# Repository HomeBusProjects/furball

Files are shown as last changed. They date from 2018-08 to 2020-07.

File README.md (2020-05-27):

# The Furball



Furball is an open-source hardware project intended to help with the research and development of [Homebus](https://github.com/HomeBusProjects), an IoT auto-provisioning framework and data processing network built on top of MQTT. Note that Homebus is not even alpha quality software at this time and is still undergoing architectural changes and development.

The name 'Furball' is an homage to Dave Mills' ["Fuzzball"](https://en.wikipedia.org/wiki/Fuzzball_router), one of the first routers on the nascent Internet.

The Furball hardware performs environmental monitoring and is intended to be deployed indoors with fixed power source. It will auto-provision with Homebus to feed sensor readings into an IoT system.

## Hardware

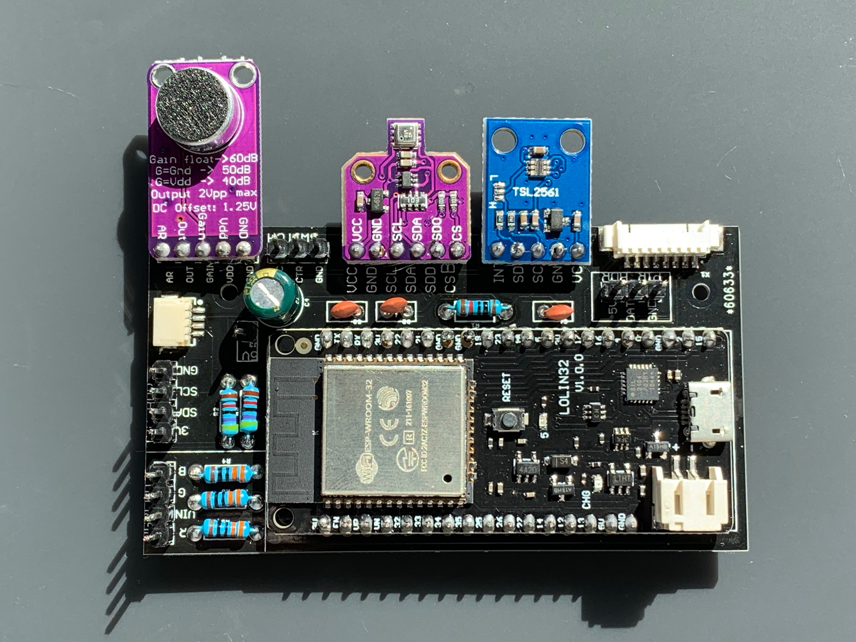
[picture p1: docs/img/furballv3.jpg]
An assembled Furball


Furball is based on the ESP32 processor. ESP32 is more capable than its predecessor, the ESP8266 while remaining inexpensive. The ESP32 supports both 802.11b/g/n Wifi and Bluetooth 4.2/BLE. It also has hardware acceleration for encryption. It includes 4 SPI controllers, 2 I2C controllers, 3 UARTs, up to 18 channels of ADC and two 8 bit DACs. You'll never use all of those at once as it doesn't have enough GPIO pins to express all of those functions, though you can map many of the hardware controllers to particular GPIO pins.

The hardware supports several environmental sensors:
- temperature
- humidity
- air pressure 
- light intensity
- occupancy 
- sound intensity
- volatile organics

It's powered via USB. The hardware currently uses a LOLIN32 board which has a JST connector for a LiPo battery. The software is currently in no way optimized for battery operation.

The hardware also includes either a tri-color LED or RGB LED with controller.

While the Furball hardware is designed to work with the Furball software, it should also work with other software like [ESPEasy32](https://www.letscontrolit.com/wiki/index.php?title=ESPEasy32), [ESPHome](https://esphome.io/) or custom software.

See the [Furball Hardware Guide](HARDWARE.md) for assembly instructions.

### Temperature, Humidity and Pressure

Furball currently uses the [BME280](https://www.bosch-sensortec.com/products/environmental-sensors/humidity-sensors-bme280/) - temperature/pressure/humidity sensor, $2.57 in single unit quantities, AliExpress, or the [BME680](https://www.bosch-sensortec.com/products/environmental-sensors/gas-sensors-bme680/) - temperature/pressure/humidity/VOC sensor, $9.92 in single unit quanitties on AliExpress.

### Occupancy

Furball hardware has a 3 pin header for a [PIR](https://en.wikipedia.org/wiki/Passive_infrared_sensor) sensor.

### Sound Pressure

Furball hardware currently uses a small amplified microphone on a breakout board, compatible with [Sparkfun's Sound Detector](https://www.sparkfun.com/products/12642).

### Light

Furball uses the [TSL2561](https://ams.com/tsl2561)  Digital Luminosity sensor - $1 in single unit quantities, AliExpress.

### VOC

Furball uses the BME680, which is a BME280 plus a VOC sensor. If you're building a Furball which can read VOCs, you only need the BME680 and not the BME280.

(note: I originally used a [CCS811](https://ams.com/ccs811) but had a lot of problems with cheaper units. It also doesn't truly measure CO2 but infers it from the VOC reading.)

### Total Cost

If bought through AliExpress, parts cost should run roughly:
- $6 - ESP32 LOLIN32
- $2.57 - BME280
- $1 - TSL2561
- $9 - BME680
- $1 - random resistors, capacitors, tri-color LED

Total of roughly $20 in parts before the circuit board.

## Optional Hardware

### Particle sensor

Furball has an optional port to connect a Plantower [PMS5003](http://www.plantower.com/en/content/?108.html) particle sensor. The particle sensor allows you to monitor air quality.

## Software

Furball's software is built on the Arduino Core using [PlatformIO](https://platformio.org/) as its build system. I prefer PlatformIO because it's fast, has a good library manager, lets you build for arbitrary platforms without having to manually install support for them, and lets you use your editor of choice.

Create a `src/config.h` file based on `src/config.h-example` and configure Wifi and the MQTT broker.

Once you've installed PlatformIO you can build the Furball firmware by running:
```
platformio run
```

in its top level directory.

To flash the firmware, run:
```
platformio run -t upload
```

It currently supports OTA updates.

## Iterations

The intial version is a simple breadboard.

Second version is a soldered printed circuit breadboard.

The third and current version will be a custom printed circuit board with modules soldered into it.

A hypothetical fourth version would be a custom printed circuit board with surface mount components and will have components mounted directly on it rather than using 3rd party modules.

# License

Software and documentation is licensed under the [MIT license](https://romkey.mit-license.org/).

Circuits are licensed under [Creative Commons Attribution Share-Alike license](https://creativecommons.org/licenses/by-sa/4.0).

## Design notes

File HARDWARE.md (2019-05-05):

# Furball Hardware Guide

The Furball is based on an ESP32 processor.

The ESP32 supports IEEE802.11b/g/n wifi as well as Bluetooth 4.0 and BLE.

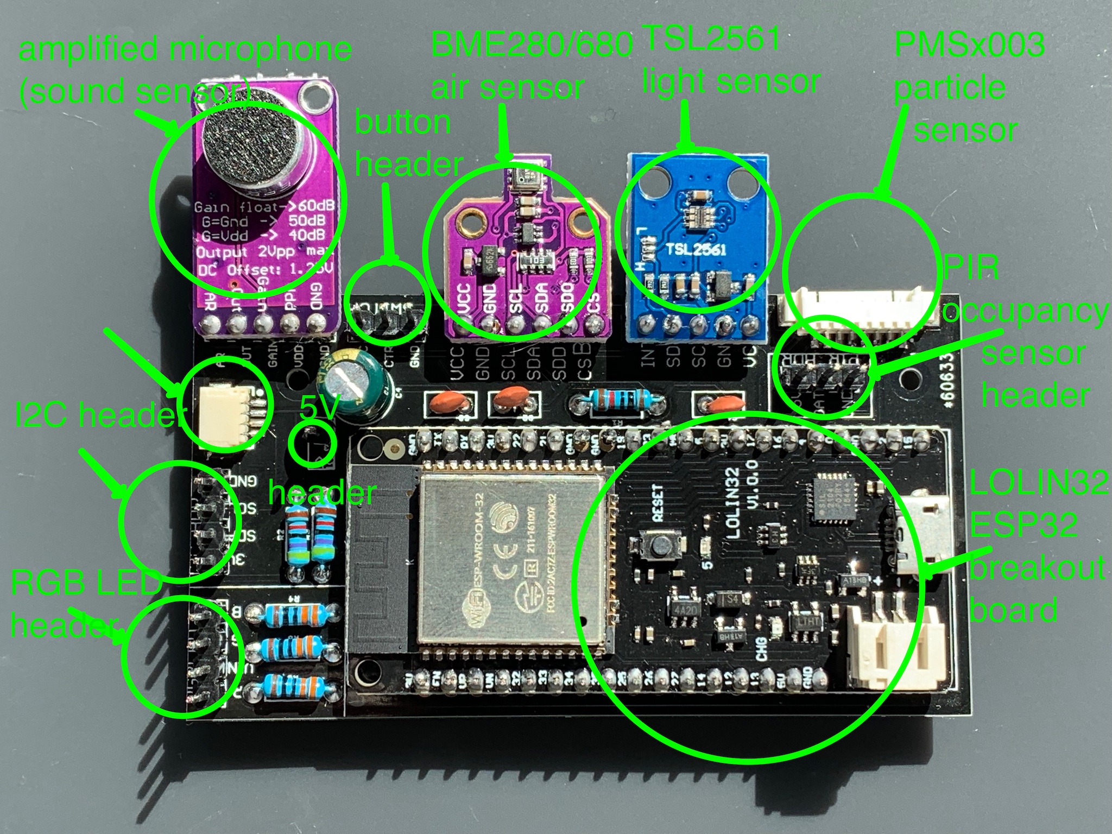
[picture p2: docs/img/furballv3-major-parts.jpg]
Furball's major parts


Furball uses I2C to communicate with a BME280 (air temperature, humidity and pressure) or BME680 (air temperature, humidity, pressure and volatile organics) and a TSL2561 (light intensity).

It also expresses the I2C bus via both a 4 pin header and a Sparkfun QUICC connector so that you can easily add external I2C devices if you want.

Furball also has a connector for a PMS5003 particle counter (via a 9600bps serial connection) and a PIR occupancy detector (via a digital input).

Furball can controll an RGB LED and can read the state of an switch (intended as a reset/factory reset button).

All of these are optional. Furball can detect the presence of a BME280, BME680, TSL2561 or external I2C device (external devices will need software support). It cannot detect whether a PIR sensor, RGB LED or switch is connected. The software also cannot currently detect whether a PMS5003 is connected but this may change with future releases.

## The printed circuit board

The Furball v4 board was designed using [Autodesk Eagle](https://www.autodesk.com/products/eagle/overview). The Eagle files are in the `eagle` directory of this repository. The board is small enough that the free version of Eagle works.

There are currently no known issues with the board but I cannot guarantee it will work 100% correctly and that no issues will be found in the future. *Use at your own risk*.

The board would benefit from better documentation on its silkscreen (resistors and capacitors are not well-labelled).

## Assembly

1. The PMS5003 and Sparkfun QUIIC connectors are both surface mount and for most people will be the most challenging part of assembling this board. They're both optional. If you're going to use them, I recommend soldering them first.  

  The technique I use is to apply solder to all the pads for both connectors using a fine tip on the soldering iron and fine solder (0.6mm).  

  Then carefully, using your fingertips or needle nose pliers or tweezers, position the connector on top of the pads and use the soldering iron to melt one of the sides. Let that cool and then carefully melt each connection until the entire connector has solid contact with the board and solder.

2. Solder headers on the ESP32 breakout board as well as the other boards that I'm using in the project.

3. Solder the ESP32 breakout board onto the printed circuit board.

4. If you're using it, solder the TSL2561 breakout board onto the main board. Then I flash the board with the [ESP32 diagnostic](), run an I2C scan and confirm that the ESP32 can see the TSL2561. If it cannot, inspect the board for bad solder joints or shorts.

5. If you're using it, solder the BME280 or BME680 onto the board and run the ESP32 diagnostic and confirm that the ESP32 can see it and (if used) the TSL2561. Resolve any problems before proceeding.

6. Solder the microphone breakout board, if being used.

7. Next, solder the resistors and capacitors on the board.

- three 330 ohm resistors
- two 47K ohm resistors
- one 10k ohm resistor
- three 10pF capacitors
- one 100

This is a good time to run the diagnostic again in order to make sure the board still works.

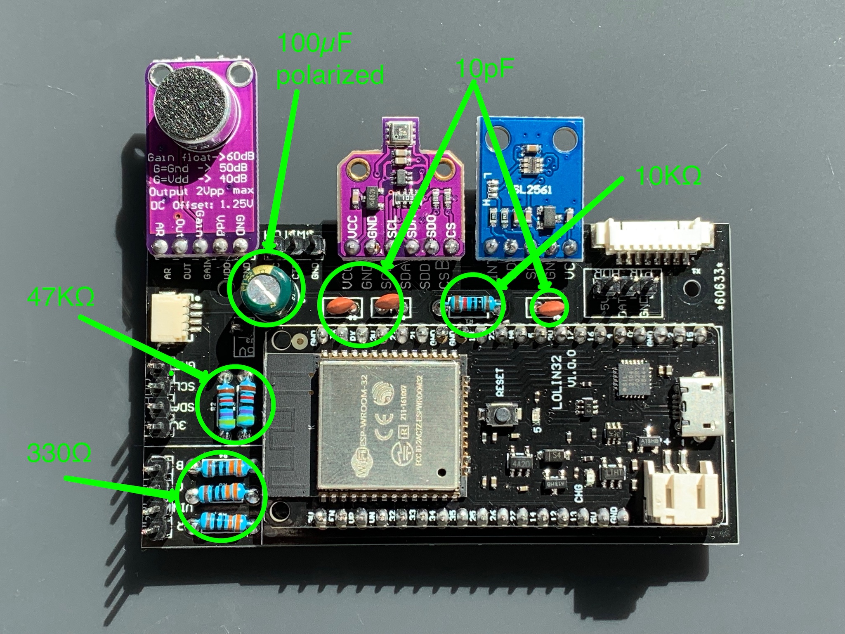
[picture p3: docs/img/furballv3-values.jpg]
Furball's resistors and capacitors


8. Finally, solder whichever headers you want to use. You can ignore ones you don't need, and you can always add them later if you want.

- external I2C - 4 pins
- RGB LED - 4 pins
- PIR sensor - 3 pins
- switch - 3 pins
- 5V - 1 pin

9. Run the diagnostic a final time and resolve any problems.

10. Build and flash the Furball firmware and watch its output to confirm that the board is working properly.

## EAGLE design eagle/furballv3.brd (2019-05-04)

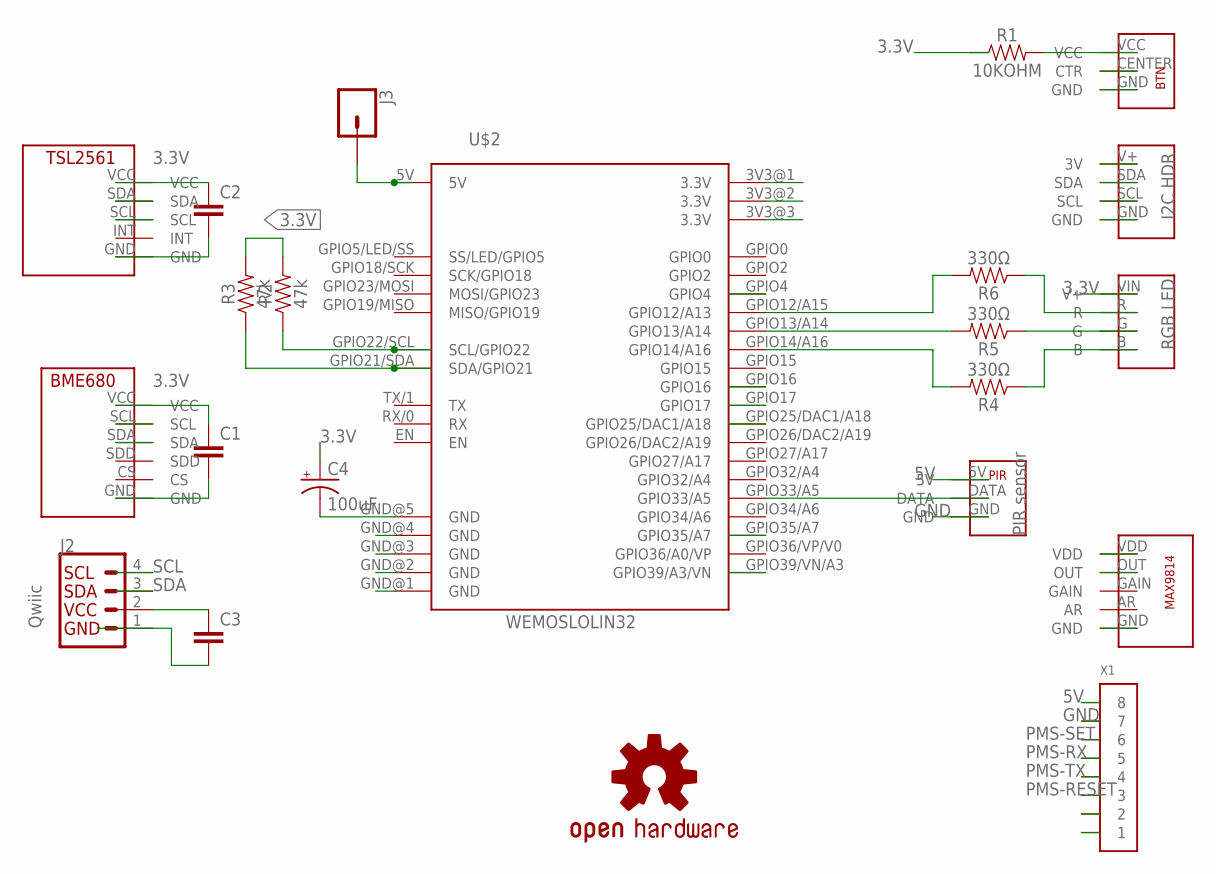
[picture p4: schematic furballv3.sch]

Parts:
C1, C2, C3: 10pF; CAP-PTH-SMALL2
C4: 100uF; CPOL-RADIAL-2.5MM-6.5MM
J2: QWIIC_CONNECTORJS-1MM; 1X04_1MM_RA
J3: CONN_01; 1X01
LOGO1: OSHW-LOGOL; OSHW-LOGO-L
R1: 10KOHM; AXIAL-0.3-KIT
R2, R3: 47k; AXIAL-0.3
R4, R5, R6: 330Ω; AXIAL-0.3
U$1: PIRHEADER
U$2: WEMOSLOLIN32; LOLIN32VAR1
U$3: BME680BREAKOUT
U$4: TSL2561BREAKOUT
U$5: RGBLEDHEADER; RGBLEDHDR
U$6: I2CHEADER
U$7: MAX9814BREAKOUT
U$8: PUSHBUTTONHEADER
X1: CONN_8-1-53261; PB-53261-08

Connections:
3.3V: C1.1, C2.1, C3.1, C4.1 (+), J2.2 (VCC), R1.P$1 (1), R2.P$2 (2), R3.P$2 (2), U$2.3V3@1 (3.3V), U$2.3V3@2 (3.3V), U$2.3V3@3 (3.3V), U$3.VCC, U$4.VCC, U$5.VIN (V+), U$6.V+ (3V), U$7.VDD
5V: J3.1, U$1.5V, U$2.5V, X1.8
BUTTON: U$2.GPIO35/A7, U$8.CENTER (CTR)
GND: C1.2, C2.2, C3.2, C4.2 (-), J2.1 (GND), U$1.GND, U$2.GND@1 (GND), U$2.GND@2 (GND), U$2.GND@3 (GND), U$2.GND@4 (GND), U$2.GND@5 (GND), U$3.GND, U$4.GND, U$6.GND, U$7.GND, U$8.GND, X1.7
unnamed: R5.P$1 (1), U$5.G
unnamed: R6.P$2 (2), U$2.GPIO12/A15 (GPIO12/A13)
unnamed: U$1.DATA, U$2.GPIO33/A5
unnamed: R5.P$2 (2), U$2.GPIO13/A14
unnamed: R4.P$2 (2), U$2.GPIO14/A16
unnamed: R4.P$1 (1), U$5.B
unnamed: R6.P$1 (1), U$5.R
unnamed: R1.P$2 (2), U$8.VCC
PMS-RESET: U$2.GPIO25/DAC1/A18, X1.3
PMS-RX: U$2.GPIO16, X1.5
PMS-SET: U$2.GPIO4, X1.6
PMS-TX: U$2.GPIO17, X1.4
SCL: J2.4 (SCL), R2.P$1 (1), U$2.GPIO22/SCL (SCL/GPIO22), U$3.SCL, U$4.SCL, U$6.SCL
SDA: J2.3 (SDA), R3.P$1 (1), U$2.GPIO21/SDA (SDA/GPIO21), U$3.SDA, U$4.SDA, U$6.SDA
SOUND: U$2.GPIO39/VN/A3 (GPIO39/A3/VN), U$7.OUT

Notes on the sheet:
Qwiic
PIR sensor
RGB LED
I2C HDR

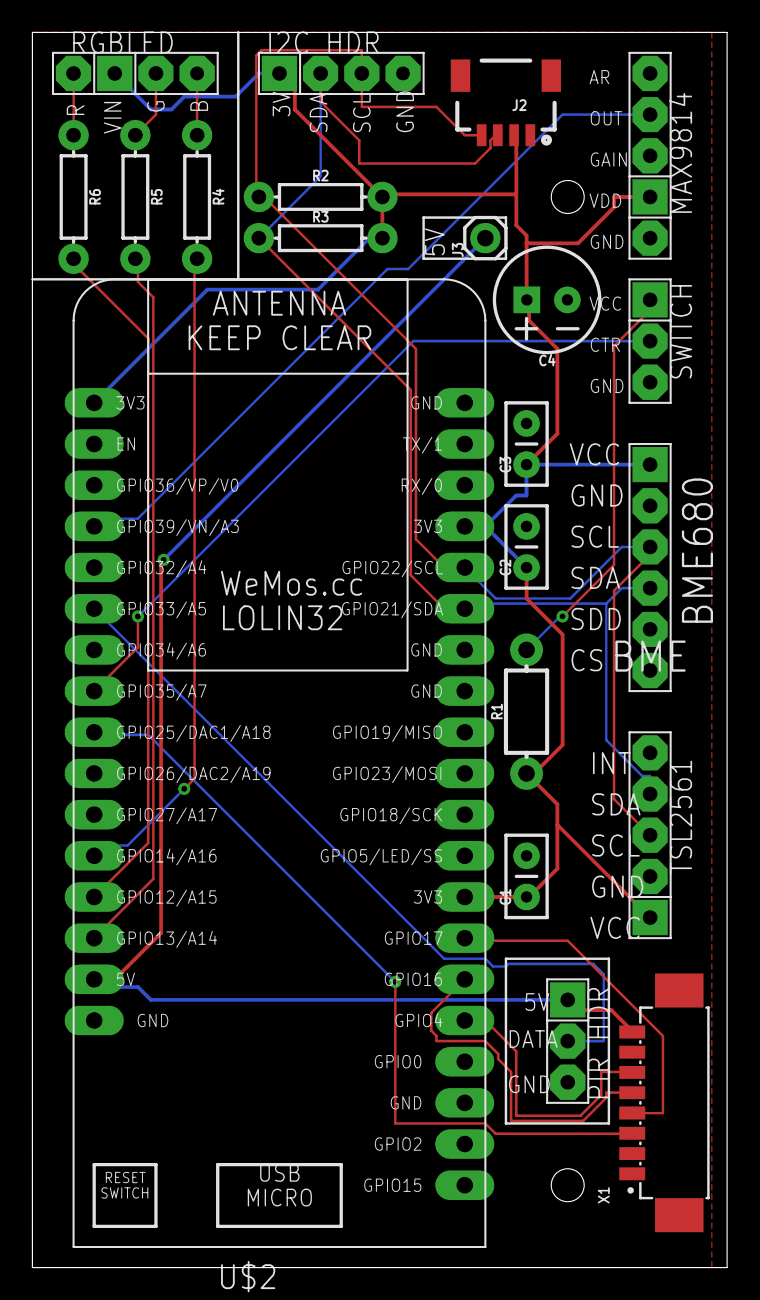
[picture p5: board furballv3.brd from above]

Board: 2 copper layers, 42.9 x 76.2 mm, 22 parts (1 on the bottom side), 19 nets.

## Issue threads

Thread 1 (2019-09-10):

Don't publish values for missing sensors

romkey, 2019-09-10:

romkey, 2020-02-19:
If a sensor isn't present, don't publish the DDC for the sensor.  For instance, if the light sensor isn't found, don't publish the 'org.homebus.light' DDC.

Closed 2020-06-27.

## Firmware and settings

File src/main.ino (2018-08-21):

#include <Arduino.h>

#include <ESP.h>
#include <ESPmDNS.h>
#include <WiFi.h>
#include <HTTPClient.h>

#include "config.h"

#include <ArduinoOTA.h>

#include "bme280_sensor.h"
#include "ccs811_sensor.h"
#include "tsl2561_sensor.h"
#include "adxl345_sensor.h"
#include "lis3dh_sensor.h"
#include "pms_sensor.h"

#include "pir_sensor.h"
#include "sound_level_sensor.h"

#define BUTTON_PIN 33
#define PIR_PIN 34
#define SOUND_PIN 35

BME280_Sensor bme280(UPDATE_DELAY, 0, 0, false);
CCS811_Sensor ccs811(UPDATE_DELAY, 0, 0, false);
TSL2561_Sensor tsl2561(UPDATE_DELAY, 0, 0, false);
ADXL345_Sensor adxl345(UPDATE_DELAY, 0, 0, false);
LIS3DH_Sensor lis3dh(UPDATE_DELAY, 0, 0, false);
PMS_Sensor pms5003(UPDATE_DELAY, 0, 0, false);

PIR_Sensor pir(1, UPDATE_DELAY, 0, 0, false);
SoundLevel_Sensor sound_level(SOUND_PIN, UPDATE_DELAY, 0, 0, false);

#include "uptime.h"

Uptime uptime;

#include <JC_Button.h>   

Button the_button(BUTTON_PIN);

// HomeBus is not ready for Prime Time so leave this out for now
#ifdef HOMEBUS

#include <HomeBus.h>
#include <HomeBusDevice.h>

HomeBus hb("Furball One",
	   "an esp8266 far, far away",
	   "HomeBus Central",
	   "0.0.1",
	   WiFi.mac_address,
	   "0-0-0-0");

HomeBusDevice hb_tsl2561_lux(&hb,
			     "Light sensor",
			     "HomeBus One",
			     100,
			     100,
			     1000,
			     true,
			     "lux",
			     "",
			     ""
			     );

HomeBusDevice hb_tsl2561_ir(&hb,
			    "Infrared sensor",
			    "HomeBus One",
			    100,
			    100,
			    1000,
			    true,
			    "ir",
			    "",
			    ""
			    );


HomeBusDevice hb_ccs811_voc(&hb,
			    "VOC",
			    "HomeBus One",
			    100,
			    100,
			    1000,
			    true,
			    "voc",
			    "",
			    ""
			    );

HomeBusDevice hb_ccs811_voc(&hb,
			    "CO2",
			    "HomeBus One",
			    100,
			    100,
			    1000,
			    false,
			    "co2",
			    "",
			    ""
			    );

#endif


#include <Adafruit_MQTT.h>
#include <Adafruit_MQTT_Client.h>

WiFiClient client;

#include <IFTTTWebhook.h>
IFTTTWebhook ifttt(IFTTT_API_KEY, IFTTT_EVENT_NAME);

Adafruit_MQTT_Client mqtt(&client, AIO_SERVER, AIO_SERVERPORT, AIO_USERNAME, AIO_KEY);

Adafruit_MQTT_Publish temperature_feed(&mqtt, AIO_USERNAME "/feeds/furball.temperature");
Adafruit_MQTT_Publish humidity_feed(&mqtt, AIO_USERNAME "/feeds/furball.humidity");
Adafruit_MQTT_Publish pressure_feed(&mqtt, AIO_USERNAME "/feeds/furball.pressure");

Adafruit_MQTT_Publish lux_feed(&mqtt, AIO_USERNAME "/feeds/furball.lux");
Adafruit_MQTT_Publish ir_feed(&mqtt, AIO_USERNAME "/feeds/furball.ir");

Adafruit_MQTT_Publish voc_feed(&mqtt, AIO_USERNAME "/feeds/furball.voc");
Adafruit_MQTT_Publish eco2_feed(&mqtt, AIO_USERNAME "/feeds/furball.eco2");

Adafruit_MQTT_Publish pir_feed(&mqtt, AIO_USERNAME "/feeds/furball.pir");
Adafruit_MQTT_Publish sound_level_feed(&mqtt, AIO_USERNAME "/feeds/furball.sound");

Adafruit_MQTT_Publish uptime_feed(&mqtt, AIO_USERNAME "/feeds/furball.uptime");
Adafruit_MQTT_Publish freeheap_feed(&mqtt, AIO_USERNAME "/feeds/furball.freeheap");


void mqtt_connect(void) {
  int8_t ret;

  return;

  Serial.print("Connecting to Adafruit IO... ");

  while ((ret = mqtt.connect()) != 0) {
    switch (ret) {
      case 1: Serial.println("Wrong protocol"); break;
      case 2: Serial.println("ID rejected"); break;
      case 3: Serial.println("Server unavail"); break;
      case 4: Serial.println("Bad user/pass"); break;
      case 5: Serial.println("Not authed"); break;
      case 6: Serial.println("Failed to subscribe"); break;
      default: Serial.println("Connection failed"); break;
    }

    if(ret >= 0)
      mqtt.disconnect();

    Serial.println("Retrying connection...");
    delay(5000);
  }

  Serial.println("Adafruit IO Connected!");
}

#include <rom/rtc.h>

char* reboot_reason(int code) {
  switch(code) {
    case 1 : return "POWERON_RESET";          /**<1, Vbat power on reset*/
    case 3 : return "SW_RESET";               /**<3, Software reset digital core*/
    case 4 : return "OWDT_RESET";             /**<4, Legacy watch dog reset digital core*/
    case 5 : return "DEEPSLEEP_RESET";        /**<5, Deep Sleep reset digital core*/
    case 6 : return "SDIO_RESET";             /**<6, Reset by SLC module, reset digital core*/
    case 7 : return "TG0WDT_SYS_RESET";       /**<7, Timer Group0 Watch dog reset digital core*/
    case 8 : return "TG1WDT_SYS_RESET";       /**<8, Timer Group1 Watch dog reset digital core*/
    case 9 : return "RTCWDT_SYS_RESET";       /**<9, RTC Watch dog Reset digital core*/
    case 10 : return "INTRUSION_RESET";       /**<10, Instrusion tested to reset CPU*/
    case 11 : return "TGWDT_CPU_RESET";       /**<11, Time Group reset CPU*/
    case 12 : return "SW_CPU_RESET";          /**<12, Software reset CPU*/
    case 13 : return "RTCWDT_CPU_RESET";      /**<13, RTC Watch dog Reset CPU*/
    case 14 : return "EXT_CPU_RESET";         /**<14, for APP CPU, reseted by PRO CPU*/
    case 15 : return "RTCWDT_BROWN_OUT_RESET";/**<15, Reset when the vdd voltage is not stable*/
    case 16 : return "RTCWDT_RTC_RESET";      /**<16, RTC Watch dog reset digital core and rtc module*/
    default : return "NO_MEAN";
  }
}
  
void setup() {
  char hostname[sizeof(FURBALL_HOSTNAME) + 8];
  byte mac_address[6];

  delay(5000);

  Serial.begin(115200);
  Serial.println("Hello World!");

  WiFi.begin(WIFI_SSID, WIFI_PASSWORD);

  WiFi.macAddress(mac_address);
  snprintf(hostname, sizeof(hostname), "%s %02x%02x%02x", FURBALL_HOSTNAME, (int)mac_address[3], (int)mac_address[4], (int)mac_address[5]);
  Serial.printf("Hostname is %s\n", hostname);

  WiFi.setHostname(hostname);
  while(!WiFi.isConnected()) {
    Serial.print(".");
    delay(100);
  }

  Serial.println();
  Serial.println("Connected!");

  ifttt.trigger("reboot", reboot_reason(rtc_get_reset_reason(0)),  reboot_reason(rtc_get_reset_reason(1)));

  if(!MDNS.begin(hostname))
    Serial.println("Error setting up MDNS responder!");
  else
    Serial.println("mDNS responder started");

  Serial.println("MQTT");
  mqtt_connect();

#ifdef ESP32
   ArduinoOTA
    .onStart([]() {
      String type;
      if (ArduinoOTA.getCommand() == U_FLASH)
        type = "sketch";
      else // U_SPIFFS
        type = "filesystem";

      // NOTE: if updating SPIFFS this would be the place to unmount SPIFFS using SPIFFS.end()
      Serial.println("Start updating " + type);
    })
    .onEnd([]() {
      Serial.println("\nEnd");
      ESP.restart();
    })
    .onProgress([](unsigned int progress, unsigned int total) {
      Serial.printf("Progress: %u%%\r", (progress / (total / 100)));
    })
    .onError([](ota_error_t error) {
      Serial.printf("Error[%u]: ", error);
      if (error == OTA_AUTH_ERROR) Serial.println("Auth Failed");
      else if (error == OTA_BEGIN_ERROR) Serial.println("Begin Failed");
      else if (error == OTA_CONNECT_ERROR) Serial.println("Connect Failed");
      else if (error == OTA_RECEIVE_ERROR) Serial.println("Receive Failed");
      else if (error == OTA_END_ERROR) Serial.println("End Failed");
    });
#endif

  ArduinoOTA.begin();

  bme280.begin();
  ccs811.begin();
  tsl2561.begin();
  adxl345.begin();
  lis3dh.begin();
  pms5003.begin(Serial1);

  pir.begin();
  sound_level.begin();

  Serial.printf("BME280 status %s\n", bme280.status_str());
  Serial.printf("CCS811 status %s\n", ccs811.status_str());
  Serial.printf("TSL2561 status %s\n", tsl2561.status_str());
  Serial.printf("ADXL345 status %s\n", adxl345.status_str());
  Serial.printf("lis3hd status %s\n", lis3dh.status_str());

  Serial.println();
  Serial.println();
  Serial.printf("PIR status %s\n", pir.status_str());
  Serial.printf("Sound level status %s\n", sound_level.status_str());

  delay(5000);
}


void loop() {
  static unsigned long last_loop = 0;

  ArduinoOTA.handle();

  bme280.handle();
  ccs811.handle();
  tsl2561.handle();
  lis3dh.handle();
  pms5003.handle();

  sound_level.handle();
  pir.handle();

  if(bme280.ready_for_update()) {
    temperature_feed.publish(bme280.temperature());
    pressure_feed.publish(bme280.pressure());
    humidity_feed.publish(bme280.humidity());

    Serial.printf("Temperature %d\n", bme280.temperature());
    Serial.printf("Pressure %d\n", bme280.pressure());
    Serial.printf("Humidity %d\n", bme280.humidity());
  }

  if(ccs811.ready_for_update()) {
    eco2_feed.publish(ccs811.eco2());
    voc_feed.publish(ccs811.voc());

    Serial.printf("ECO2 %d\n", ccs811.eco2());
    Serial.printf("VOC %d\n", ccs811.voc());
  }

  if(tsl2561.ready_for_update()) {
    lux_feed.publish(tsl2561.lux());
    ir_feed.publish(tsl2561.ir());

    Serial.printf("IR %d\n", tsl2561.ir());
    Serial.printf("Visible %d\n", tsl2561.visible());
    Serial.printf("Full %d\n", tsl2561.full());
    Serial.printf("Lux %d\n", tsl2561.lux());
  }

  if(lis3dh.ready_for_update()) {
    Serial.printf("LIS3DH x %d\n", lis3dh.accel_x());
    Serial.printf("LIS3DH y %d\n", lis3dh.accel_y());
    Serial.printf("LIS3DH z %d\n", lis3dh.accel_z());
  }

  if(adxl345.ready_for_update()) {
    Serial.printf("ADXL345 x %d\n", adxl345.accel_x());
    Serial.printf("ADXL345 y %d\n", adxl345.accel_y());
    Serial.printf("ADXL345 z %d\n", adxl345.accel_z());
  }

  if(pms5003.ready_for_update()) {
    Serial.printf("PMS5003 1.0 %d\n", pms5003.density_1_0());
    Serial.printf("PMS5003 2.5 %d\n", pms5003.density_2_5());
    Serial.printf("PMS5003 10.0 %d\n", pms5003.density_10_0());
  }

  if(sound_level.ready_for_update()) {
    //    sound_level_feed.publish(sound_level.sound_level());
    //    Serial.printf("Sound level %d\n", sound_level.sound_level());

    sound_level_feed.publish(sound_level.sample_value());
    Serial.printf("Sound level %d with %d samples\n", sound_level.sample_value(), sound_level.sample_count());
    sound_level.start_sampling();
  }

  if(millis() - last_loop < UPDATE_DELAY)
    return;

  last_loop = millis();

  if(! mqtt.ping(3)) {
    if(! mqtt.connected())
      mqtt_connect();
  }

  uptime_feed.publish((unsigned)uptime.uptime()/1000);
  Serial.printf("Uptime %.2f seconds\n", uptime.uptime() / 1000.0);

  freeheap_feed.publish(ESP.getFreeHeap());
  Serial.printf("Free heap %u bytes\n", ESP.getFreeHeap());

#ifdef REST_API_ENDPOINT
  char buffer[500];
  snprintf(buffer, 500, "{\"temperature\": %d, \"humidity\": %d, \"pressure\": %d, \"eco2\": %d, \"tvoc\": %d, \"pm1\": %d, \"pm25\": %d, \"pm10\": %d, \"freeheap\": %d, \"uptime\": %lu, \"lux\": %d, \"full_light\": %d, \"ir\": %d, \"visible\": %d }",
	   bme280.temperature(), bme280.humidity(), bme280.pressure(),
	   ccs811.eco2(), ccs811.voc(), 
	   pms5003.density_1_0(), pms5003.density_2_5(), pms5003.density_10_0(),
	   ESP.getFreeHeap(), uptime.uptime()/1000,
	   tsl2561.lux(), tsl2561.full(), tsl2561.ir(), tsl2561.visible());

    Serial.println(buffer);
    post(buffer);
#endif
}

void post(char *json) {
  HTTPClient http;

  http.begin(String(REST_API_ENDPOINT));
  http.addHeader("Content-Type", "application/json");
  int response = http.POST(json);
  if(response > 0) {
    Serial.printf("HTTP status code %d\n", response);
  } else {
    Serial.printf("HTTPClient error %d\n", response);
  }

  http.end();
}

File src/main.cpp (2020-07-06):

#include <Arduino.h>

#include "config.h"
#include "hw.h"

#include <multiball/app.h>
#include <multiball/wifi.h>
#include <multiball/ota_updates.h>
#include <multiball/homebus.h>

#ifdef USE_DIAGNOSTICS
#include <diagnostics.h>
#endif

#include <ESPmDNS.h>

#include <FS.h>
#include <SPIFFS.h>

#include "furball.h"

MultiballApp App;

void setup() {
  const wifi_credential_t wifi_credentials[] = {
    { WIFI_SSID1, WIFI_PASSWORD1 },
    { WIFI_SSID2, WIFI_PASSWORD2 },
    { WIFI_SSID3, WIFI_PASSWORD3 }
  };

  delay(500);

  App.wifi_credentials(3, wifi_credentials);
  App.begin("furball");
  Serial.println("[app]");

#ifdef MQTT_HOST
  Serial.println("[credentials]");
  homebus_stuff(MQTT_HOST, MQTT_PORT, MQTT_USER, MQTT_PASS, MQTT_UUID);
#endif

  Serial.println("[homebus]");
  homebus_configure("Furball", "CTRLH Electronics Lab", "Homebus", "v4");
  homebus_setup();

  furball_setup();
  Serial.println("[furball]");

#ifdef USE_DIAGNOSTICS
  diagnostics_setup();
  Serial.println("[diagnostics]");
#endif

  delay(500);
}

void loop() {
  App.handle();

  furball_loop();

#ifdef USE_DIAGNOSTICS
  diagnostics_loop(furball_stream);
#endif
}

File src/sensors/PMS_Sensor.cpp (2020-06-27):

#include "hw.h"
#include "pms_sensor.h"

void PMS_Sensor::begin(HardwareSerial port) {
  port.begin(9600, (uint32_t)SERIAL_8N1, 25, 26);

  // 16 - ESP32 xmt
  // 17 - ESP32 rcv
  _pms = new Pmsx003(17, 16);
  _pms->begin();
  _pms->waitForData(Pmsx003::wakeupTime);
  _pms->write(Pmsx003::cmdModeActive);

  // should really perform some kind of test for presence
  _present = true;
}

void PMS_Sensor::begin() {
}

#define PMS_READ_DELAY 1000

static auto lastRead = millis();

void PMS_Sensor::handle() {
  if(millis() - _last_read_request < PMS_READ_DELAY)
    return;

    const auto n = Pmsx003::Reserved;
    Pmsx003::pmsData data[n];

    Pmsx003::PmsStatus status = _pms->read(data, n);

    switch (status) {
    case Pmsx003::OK: {
#ifdef VERBOSE
      Serial.println("_________________");
      auto newRead = millis();
      Serial.print("Wait time ");
      Serial.println(newRead - _last_read_request);

      // For loop starts from 3
      // Skip the first three data (PM1dot0CF1, PM2dot5CF1, PM10CF1)
      for (size_t i = Pmsx003::PM1dot0; i < n; ++i) { 
	Serial.print(data[i]);
	Serial.print("\t");
	Serial.print(Pmsx003::dataNames[i]);
	Serial.print(" [");
	Serial.print(Pmsx003::metrics[i]);
	Serial.print("]");
	Serial.println();
      }

#endif

      _density_1_0 = data[0];
      _density_2_5 = data[1];
      _density_10_0 = data[2];

      break;
    }
    case Pmsx003::noData:
      break;
    default:
      Serial.println("_________________");
      Serial.println(Pmsx003::errorMsg[status]);
    };

    _last_read_request = millis();
}

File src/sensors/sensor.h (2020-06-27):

#pragma once

#include <Arduino.h>

class Sensor {
 public:
 Sensor(uint16_t update_frequency, uint16_t accuracy, uint16_t precision, boolean calibrated) : _update_frequency(update_frequency), _accuracy(accuracy), _precision(precision), _calibrated(calibrated) { };

  virtual void begin();
  virtual void handle();

  enum sensor_status {
    SENSOR_OKAY = 0,
    SENSOR_NOT_FOUND = 1,
    SENSOR_NOT_READY = 2,
    SENSOR_BURN_IN = 3,
    SENSOR_RUN_IN = 4,
    SENSOR_INVALID_VALUE = 5,
    SENSOR_FAULT = 6
  };

  virtual enum sensor_status status() { return _status; };

  virtual const char* status_str() {
    switch(_status) {
    case SENSOR_OKAY:
      return "Sensor okay";
    case SENSOR_NOT_FOUND:
      return "Sensor not found";
    case SENSOR_NOT_READY:
      return "Sensor not ready";
    case SENSOR_BURN_IN:
      return "Sensor still in burn-in period";
    case SENSOR_RUN_IN:
      return "Sensor still in run-in period";
    case SENSOR_INVALID_VALUE:
      return "Sensor returned an invalid reading";
    case SENSOR_FAULT:
      return "Sensor did not operate correctly";
    default:
      return "Unknown status value";
    }
  };

  virtual boolean ready_for_update() { if(_status == SENSOR_NOT_FOUND) return false; if( (millis() - _last_checked) >= _update_frequency) return true; else return false; };

  boolean is_present() { return _present; };

 protected:
  void _mark_read() { _last_checked = millis(); };

  enum sensor_status _status;

  uint16_t _update_frequency = 0;
  
  uint16_t _burn_in_time = 0;
  uint16_t _run_in_time = 0;

  uint16_t _accuracy = 0;
  uint16_t _precision = 0;
  boolean _calibrated = false;

  uint32_t _last_checked = 0;

  boolean _present = false;
};

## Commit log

2018-07-15 Hello World!
    [furball.fzz]
2018-08-21 added REST API support
    many sensor updates
2019-05-04 added Eagle schematics and some hardware documentation
    clean up unused drivers
    clean up path through main
    clean up JSON
    [furball.fzz, furballv3.brd, furballv3.sch]
2019-05-04 missed a couple of debug messages
    [main.cpp]
2019-05-08 switch to PubSubClient, drop Adafruit IO support
    publish UUID in JSON
2019-05-30 testing different PMS5003 driver
    new script to report build info
    PlatformIO build options changed to include build info
    system attribute now includes build info
2019-06-22 add BME680 library to platformio.ini
    tune BM280 and BME680 configurations to indoor use cases
    get temperature, humidity and pressure as floats, report with 1 decimal place of precision
2019-07-06 clean up platformio.ini
    start to use a HomeBus endpoint for publishing to MQTT
    sound level sensor should always use 32 bit values
2019-07-19 removed unused sensor
2019-07-28 cleanup platformio.ini
    make pubsubclient available outside of main
    cleanup/clarify sound sensor code
2019-08-03 moved sensors into their own directory
    eliminated JC_Button and IFTTTWebhook
2019-09-02 led indicator
2019-10-20 added FastLED for indicator
    reactored for MultiballApp
    fixed obscure argument order issue for Led
    [main.cpp]
2020-06-26 get rid of indicator
    make platformio do a deep scan of dependencies (fixes missing Ticker.h problem)
    [main.cpp]
2020-06-27 added is_present() support for sensors
    only update sensor readings if the sensor is present
2020-06-27 new ADSL1115 ADC support

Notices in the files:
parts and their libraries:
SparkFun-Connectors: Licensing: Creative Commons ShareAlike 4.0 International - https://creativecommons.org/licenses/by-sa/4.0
